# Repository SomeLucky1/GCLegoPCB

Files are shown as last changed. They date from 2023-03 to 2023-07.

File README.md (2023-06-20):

# Gaggiuino LegoPCB

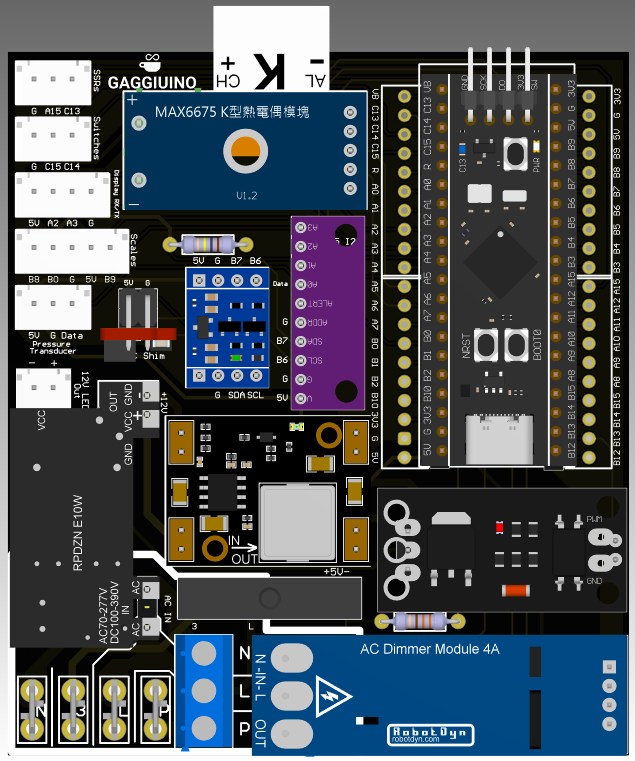
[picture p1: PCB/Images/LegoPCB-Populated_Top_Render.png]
Fully Populated


Gaggiuino has two options for assembly, "Lego" and PCB. While a nice case is available for the Lego components, there is not a good way to keep it looking clean. The primary objective of this project is to provide an option of using the Lego components, with minimal modifiction, and avoid the interconnected wire mess. LegoPCB effectively provides a wire harness on a PCB for the most of the Lego components. An SSR has been substituted as the relay used for the solenoid valve.

---
<br>

## Projects
- ### [CircuitMaker](https://workspace.circuitmaker.com/Projects/Details/somelucky/Gaggiuino-Lego-PCB-QWIIC)

- ### [PCBWay](https://www.pcbway.com/project/shareproject/Gaggiuino_Lego_PCB_872e6bd4.html)

- ### [Gaggiuino](https://gaggiuino.github.io/#/)

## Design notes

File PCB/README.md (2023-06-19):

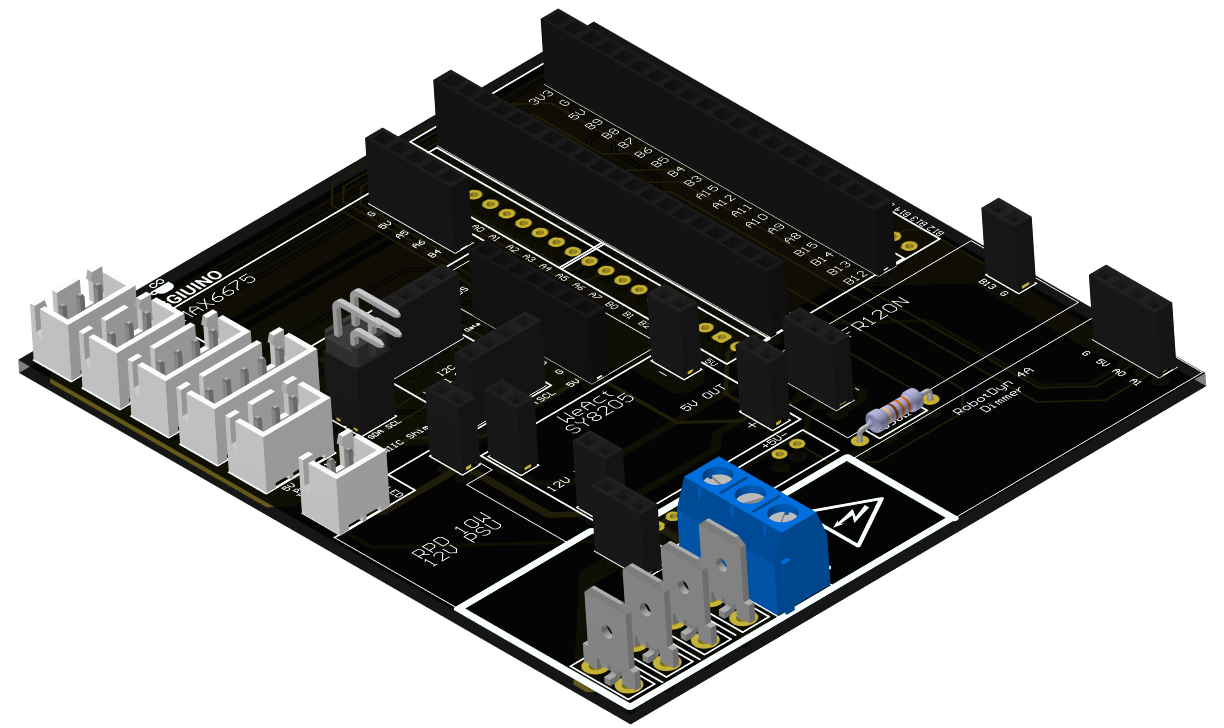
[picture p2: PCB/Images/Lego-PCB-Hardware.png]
PCB Populated


Top|Bottom
:---:|:---:
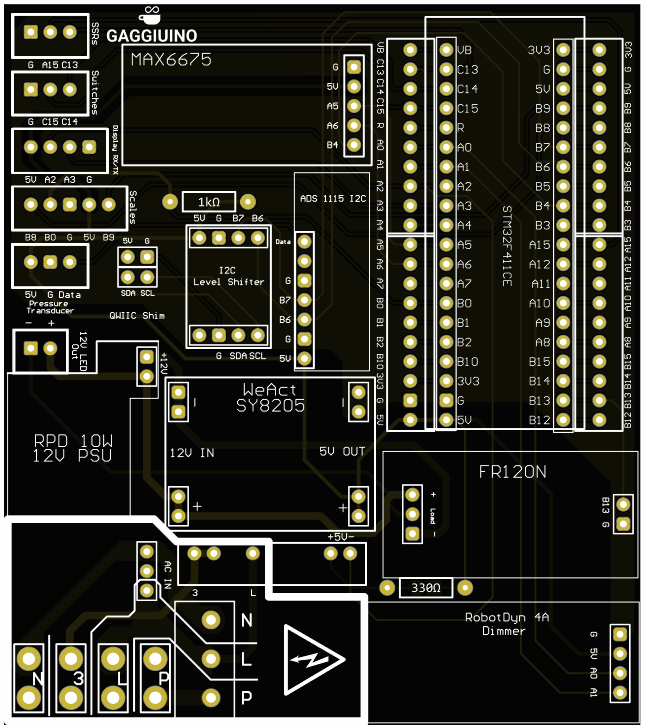
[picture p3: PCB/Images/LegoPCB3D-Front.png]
PCB Front
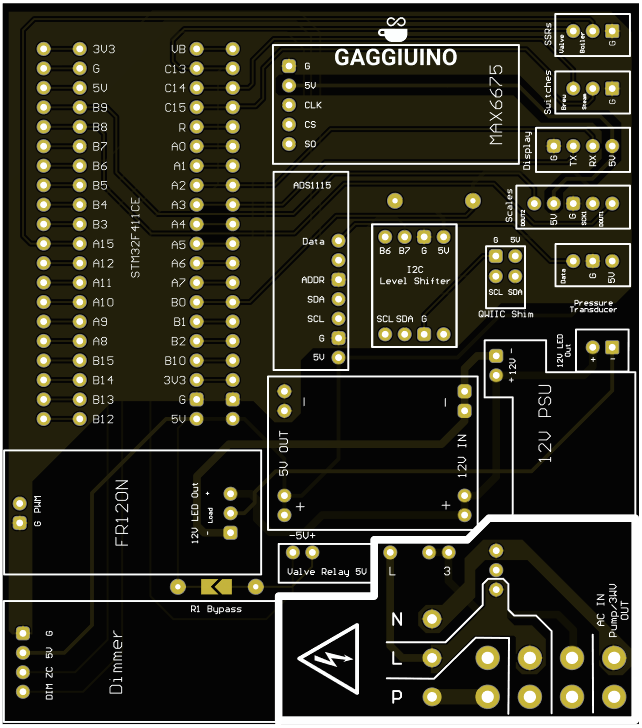
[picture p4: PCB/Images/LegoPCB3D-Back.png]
PCB Back
|

<a name="comingsoon">

### <b>Coming Soon</b> 

QWIIC connector with I²C 3.3V regulation.

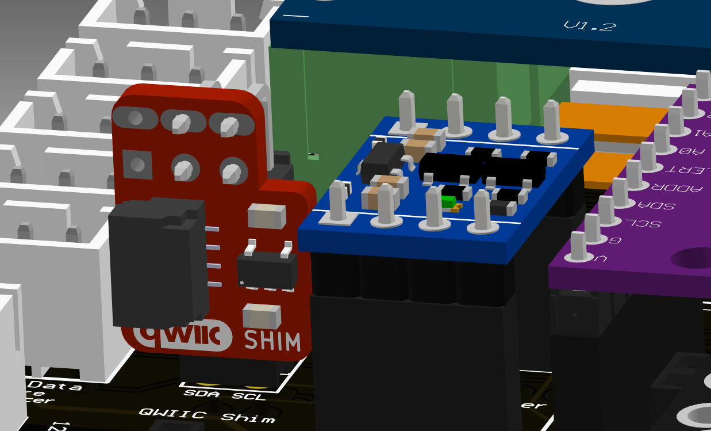
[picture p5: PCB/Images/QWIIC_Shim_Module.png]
QWIIC Module

</a>

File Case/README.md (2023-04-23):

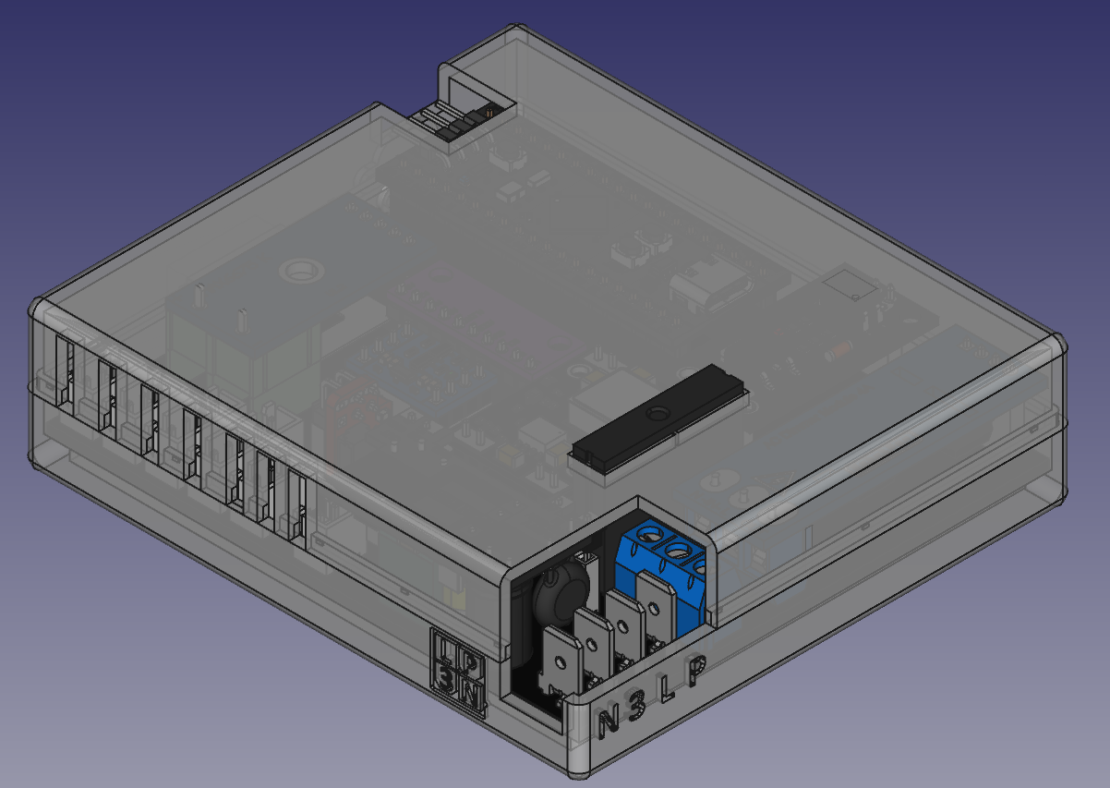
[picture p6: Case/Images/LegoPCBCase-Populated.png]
Case with PCB


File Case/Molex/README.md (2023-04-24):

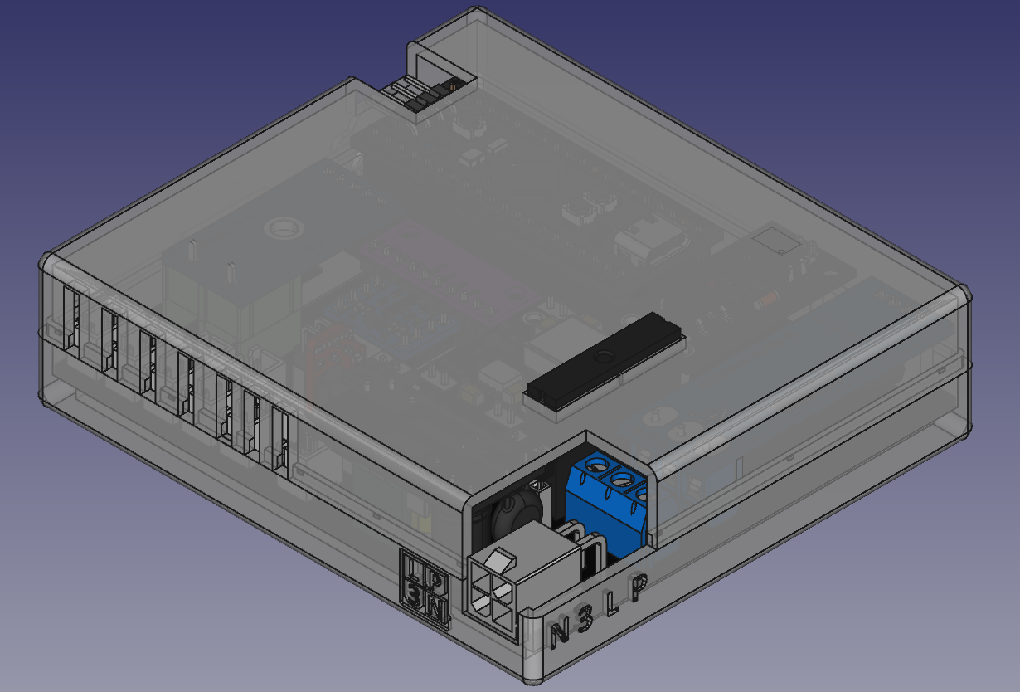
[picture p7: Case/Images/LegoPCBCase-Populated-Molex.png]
PCB Case - Molex

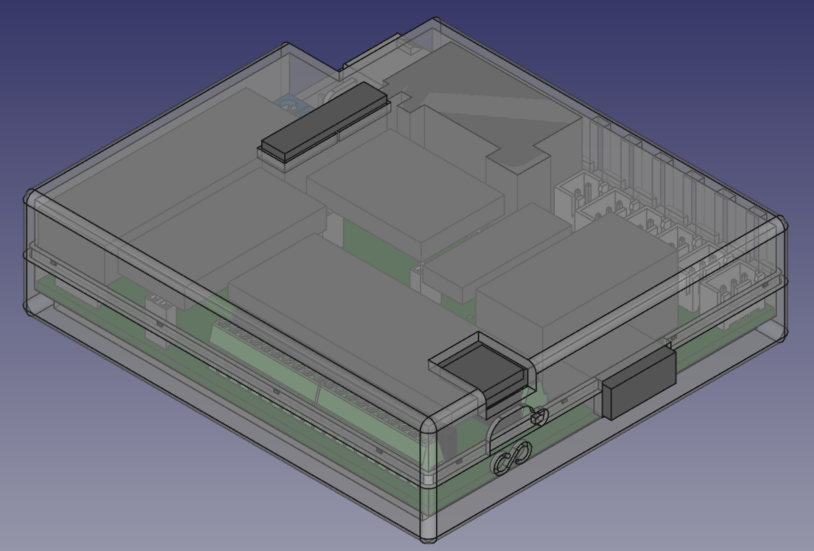
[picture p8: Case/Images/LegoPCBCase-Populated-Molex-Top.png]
PCB Case - Molex


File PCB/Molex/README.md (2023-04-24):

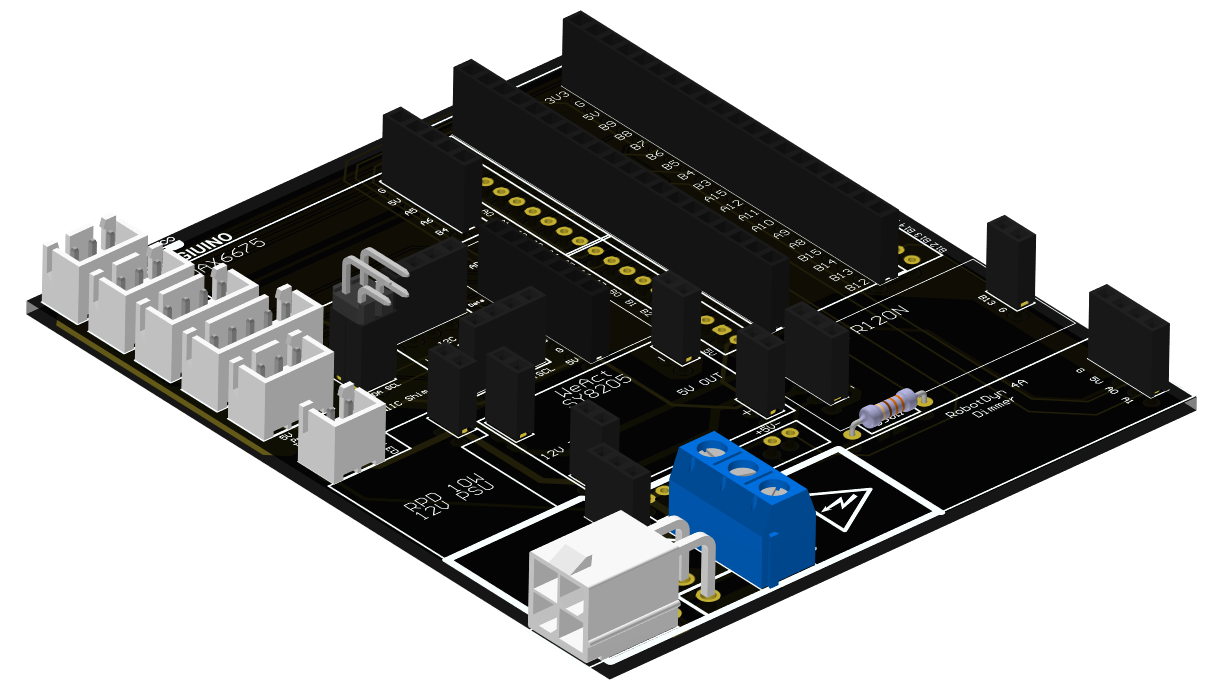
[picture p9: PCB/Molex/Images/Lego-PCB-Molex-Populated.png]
Lego PCB-Molex-Populated

Top|Bottom
:---:|:---:
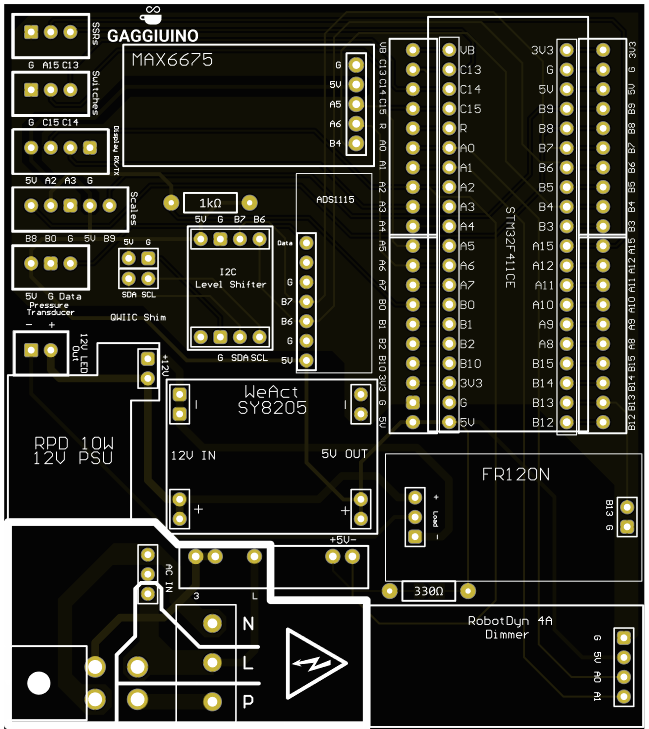
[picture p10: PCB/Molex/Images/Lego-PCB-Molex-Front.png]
Lego PCB-Molex-Front
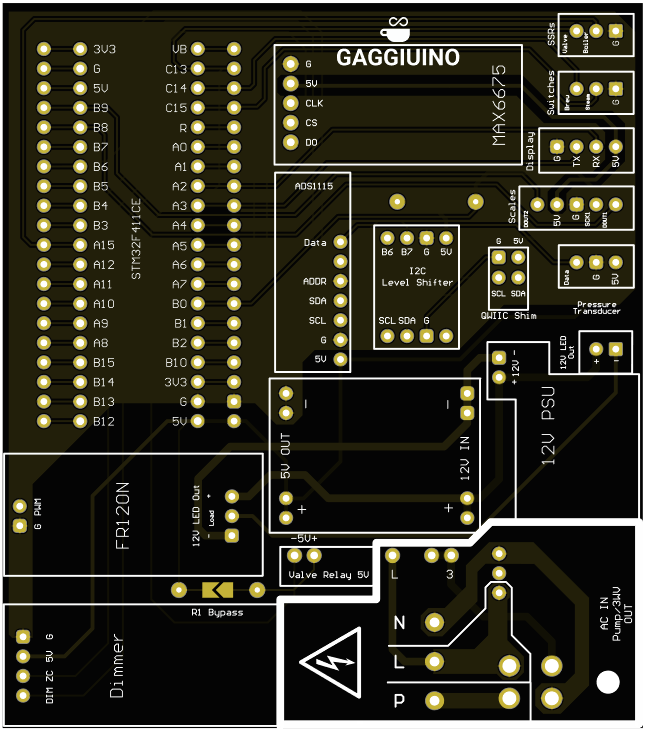
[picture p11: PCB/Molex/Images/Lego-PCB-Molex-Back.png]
Lego PCB-Molex-Back
|

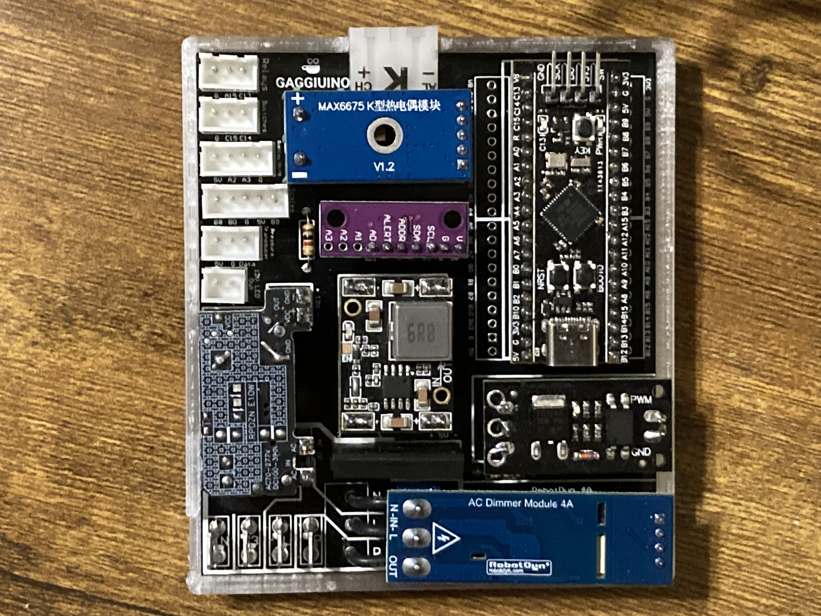
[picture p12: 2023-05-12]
PCB/Images/LegoPCB_Populated.JPG

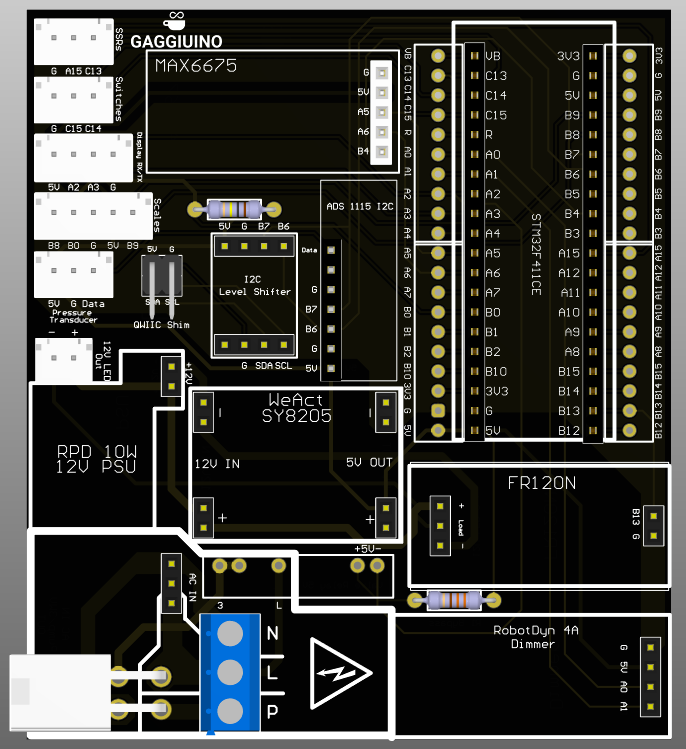
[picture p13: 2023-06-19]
PCB/Molex/Images/LegoPCB-Molex-QWIIC-Top.png

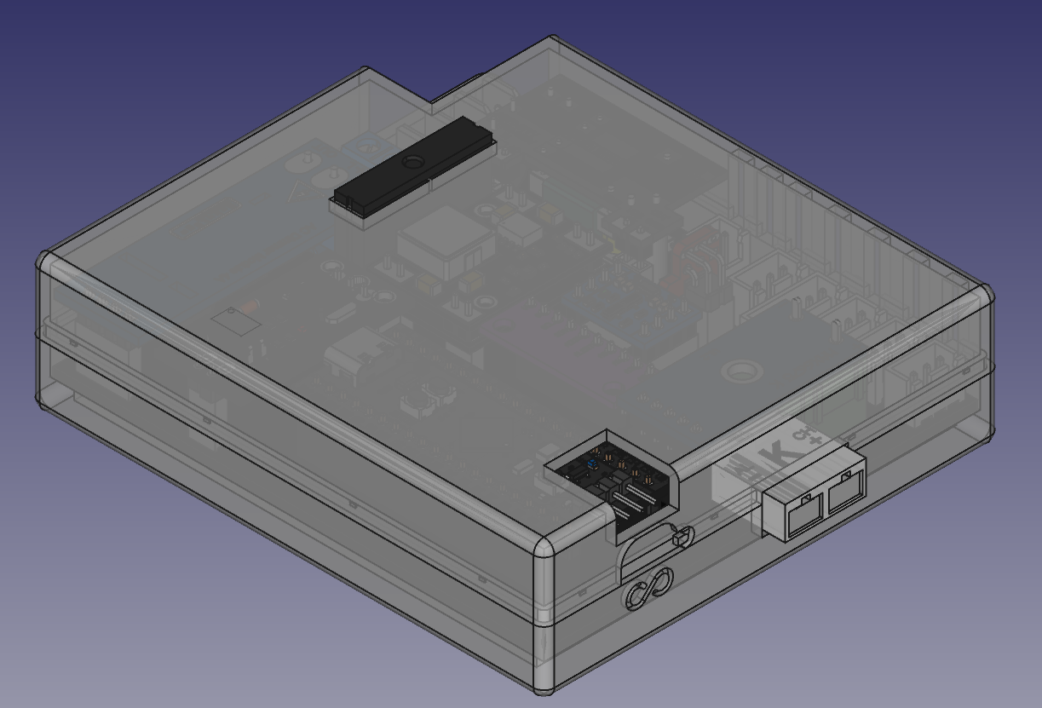
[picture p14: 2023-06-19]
Case/Images/LegoPCBCase-Populated-Top.png

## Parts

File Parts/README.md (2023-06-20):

## Soldered Components

- ### JST-XH 2.54mm Male Headers
    - 3x 3P (Boiler SSR,Brew/Steam Switches,Pressure Transducer)
    - 1x 2P (12V LED)
    - 1x 4P (Display)
    - 1x 5P (Scales)
    
    <br>
- ### Male Pin Headers
    - 28x 11.5mm
    - 4x 15mm
    - (optional) 1x 2x2 right angle 3mm/6mm board/header

    <br>
- ### Female Pin Headers
    - 8x 2P (5V PSU,12V PSU,FR120N, QWIIC Shim)
    - 2x 20P (Blackpill)
    - 2x 3P (12V PSU,FR120N)
    - 1x 7P (ADS1115)
    - 1x 5P (MAX6675)
    - 3x 4P (Dimmer, I²C Shifter)

    <br>
- ### Screw Terminals
    - 1x 3P 5mm pitch - Bundled with most FR120N preassembled boards
    - (optional) 4x 10P 2.54mm pitch

    <br>
- ### Power/3WV/Pump Connections
    - 4x Male blade quick connect terminals
    - (optional) Molex 4P Mini Fit Jr. 90 degree mount -- for use with Molex Power design PCB

    <br>
- ### Resistors ¼W
    - 1x 1kΩ - for use with hardware scales
    - (optional) 1x 330Ω - If 3WV SSR requires

    <br>
- ### 3-Way Solenoid Valve SSR (choose one)
    - Omron G3MB-202P 5V - No input resistor requried (short R1 Bypass solder pad)
    - Panasonic AQG12105 - Input resistor required

    <br>

## Lego Part Modifications
Part|3D Model|Mod
---|---|---
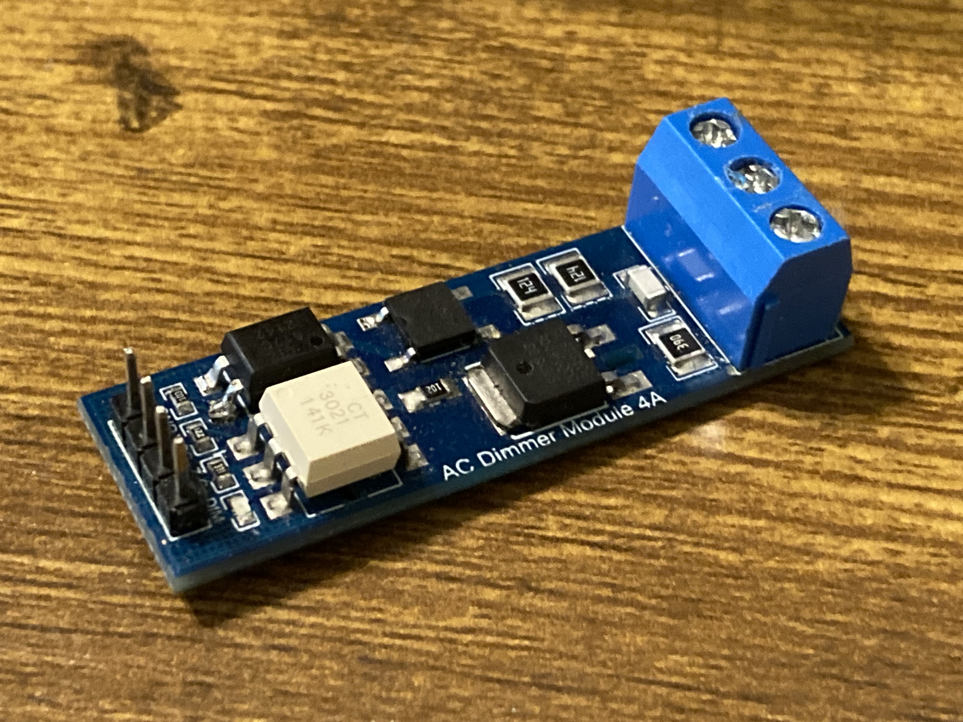
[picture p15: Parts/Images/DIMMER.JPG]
Dimmer
|[STL](/Parts/Images/STL/RDDimmer.stl "Dimmer") <br> [STEP](/Parts/Images/STEP/RDDimmer.step "Dimmer")|No modifications required
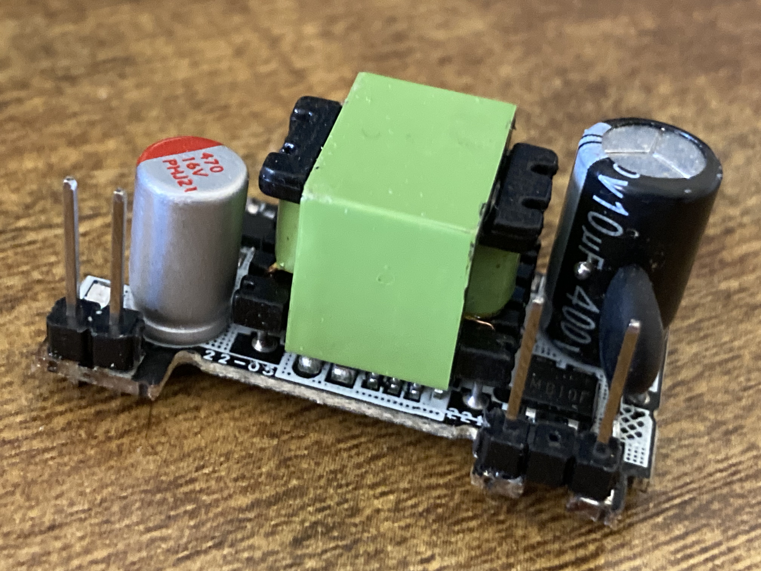
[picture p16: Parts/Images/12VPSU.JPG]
12V PSU
|[STL](/Parts/Images/STL/12V1APSU.stl "12VPSU") <br> [STEP](/Parts/Images/STEP/12V1APSU.step "12VPSU")|Use 15mm male pin headers
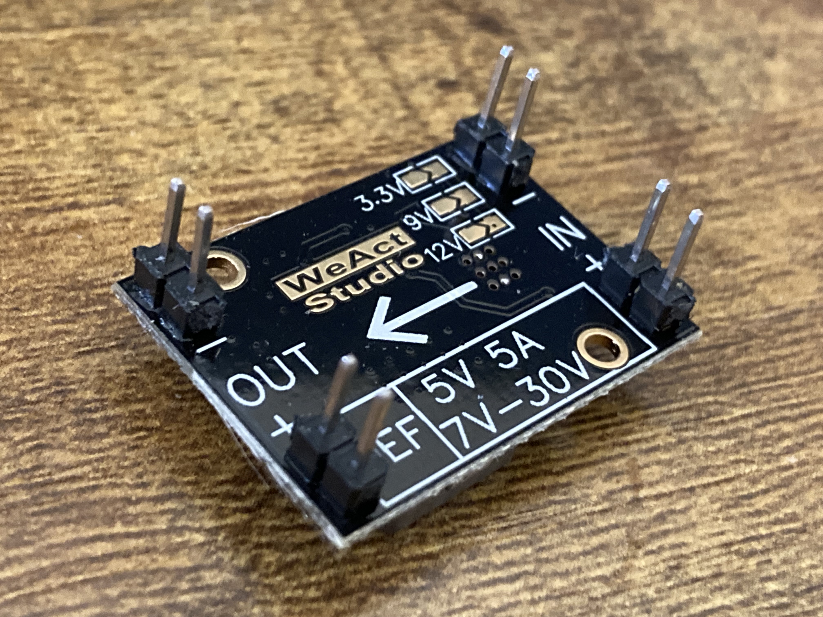
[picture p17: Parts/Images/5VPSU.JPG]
5V PSU
|[STL](/Parts/Images/STL/SY8205.stl "5VPSU") <br> [STEP](/Parts/Images/STEP/SY8205.step "5VPSU")|Use 11.5mm male pin headers
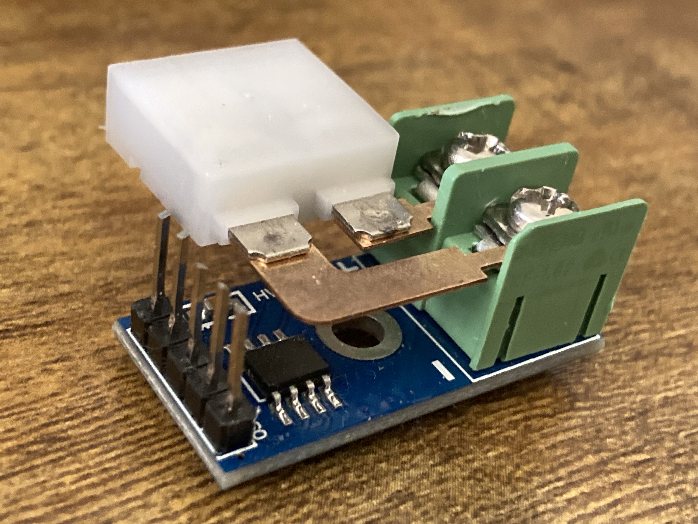
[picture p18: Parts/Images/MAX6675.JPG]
MAX6675
|[STL](/Parts/Images/STL/MAX6675.stl "MAX6675") [STL](/Parts/Images/STL/KPlugPCBMount.stl "KPLUG")<br> [STEP](/Parts/Images/STEP/MAX6675BB.step "MAX6675") [STEP](/Parts/Images/STEP/KPlugPCBMount.step "KPLUG")|Straighten pins<br><br>(optional) Use PCB mountable female mini K-type plug
TCM4 TC Sensor - M4||(optional) Use male mini K-type plug
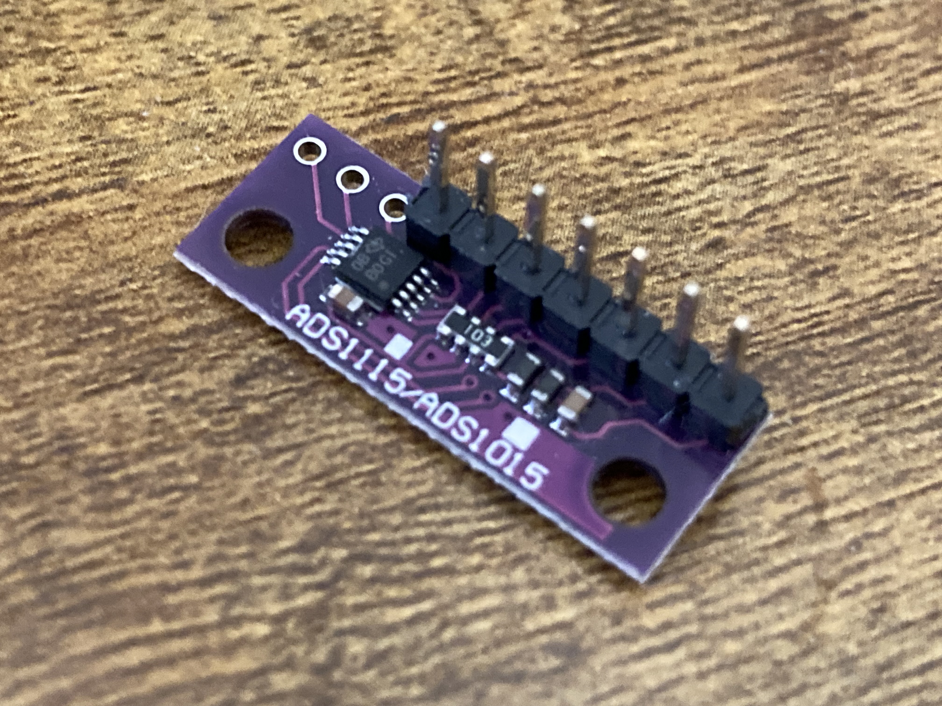
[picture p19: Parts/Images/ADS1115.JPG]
ADS1115
|[STL](/Parts/Images/STL/ADS1115.stl "ADS1115") <br> [STEP](/Parts/Images/STEP/ADS1115BB.step "ADS1115")|Use 11.5mm male pin headers
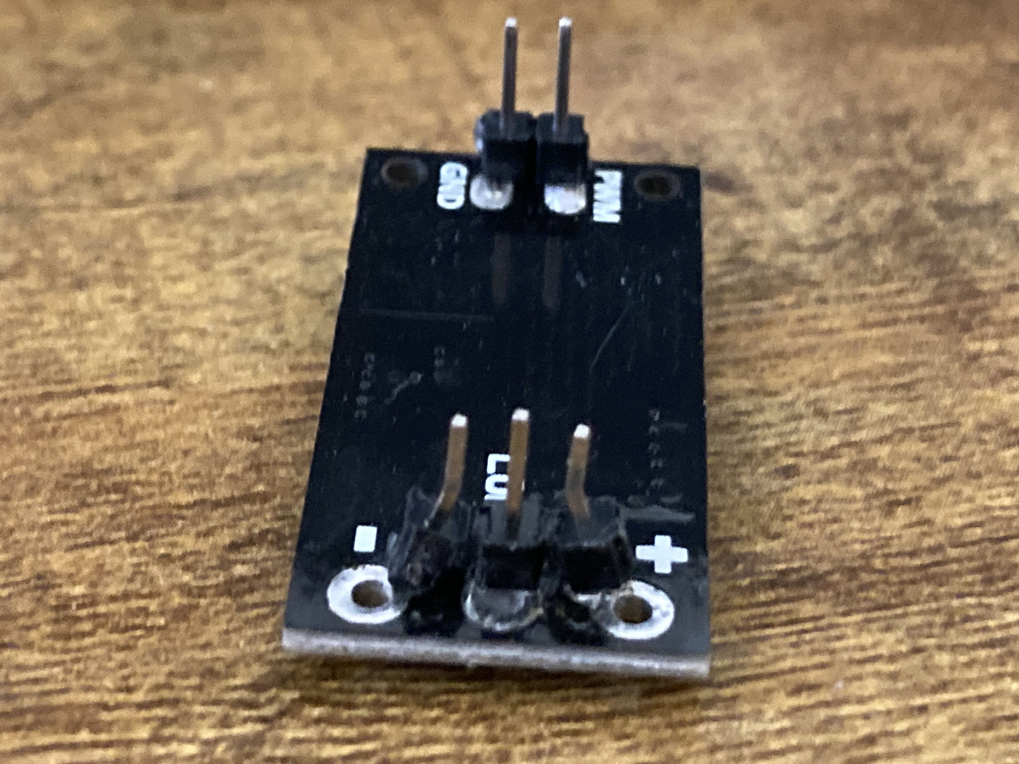
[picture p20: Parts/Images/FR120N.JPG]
FR120N
|[STL](/Parts/Images/STL/MosfetBoard.stl "FR120N") <br> [STEP](/Parts/Images/STEP/MosfetBoard.step "FR120N")|Use 11.5mm male pin headers<br><br>Bend 12V/Load pins to 2.54mm pitch width
QWIIC SHIM|[STL](/Parts/Images/STL/LevelConverter.stl "Level Shifter") [STL](/Parts/Images/STL/QWIICShim.stl "QWIIC Shim") <br> [STEP](/Parts/Images/STEP/LevelConverter.step "Level Shifter") [STEP](/Parts/Images/STEP/QWIIC%20SHIM.step "QWIIC Shim")|  Qwiic connector and I²C 3.3V regulation module.

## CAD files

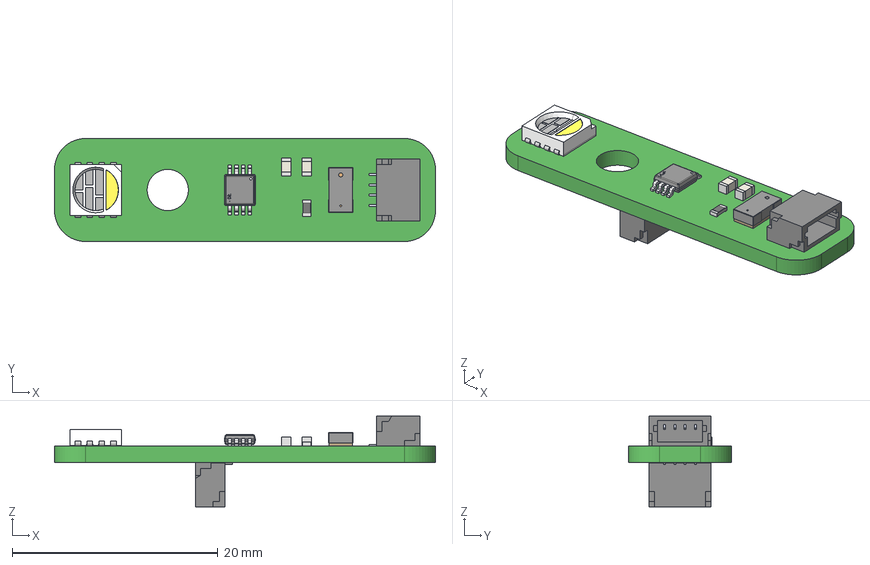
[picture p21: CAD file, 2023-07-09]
Accessories/Images/STEP/ToFnLED-RGBW.step
37.0 x 10.0 x 8.80 mm
NXP Logo
Solder Mask Ext
PCB
Solder Pads
Large Sensor Cover
Small Sensor Cover
Chamfered Case
User Library-res0603-1
SPARKFUN_QWIIC_RIGHT_ANGLE
Conn_JST_BM04B-SRSS-TB_LF_SN_eec_RGB4210752
LED Traces
White LED
Pin7
Pin3
Pin4
Pin2
Pin1
Pin5
Pin6
Pin8
Extruded x 6

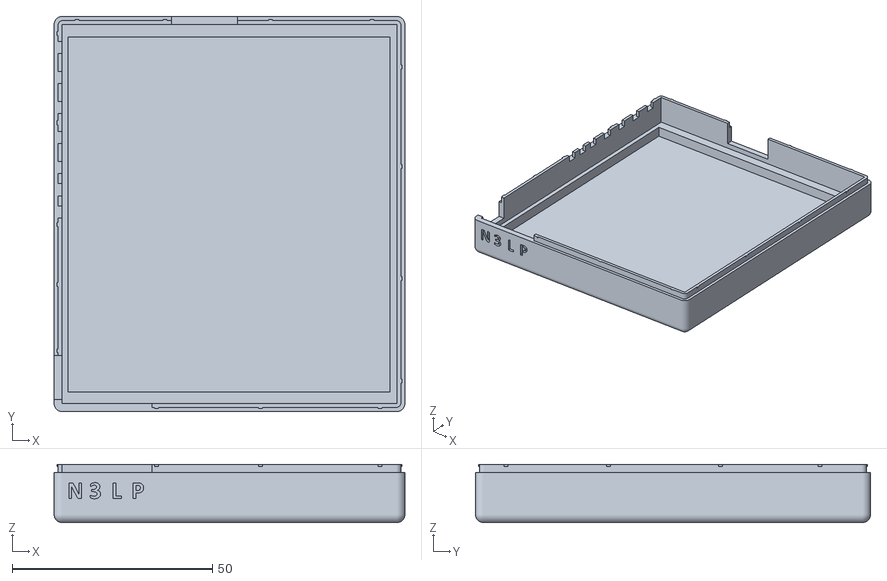
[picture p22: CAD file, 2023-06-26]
Case/PCB Case-Bottom.stl
87.5 x 98.5 x 14.5

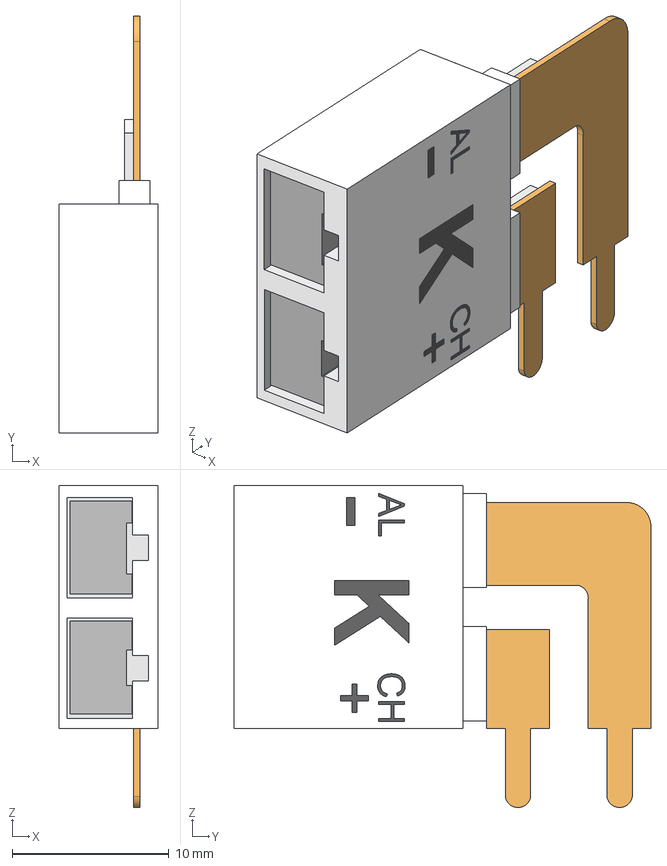
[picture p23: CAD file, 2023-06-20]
Parts/Images/STEP/KPlugPCBMount.step
6.35 x 26.6 x 20.5 mm
Pin Mounts
Joints
Pins Ext
Clamps
K
AL
CH
+

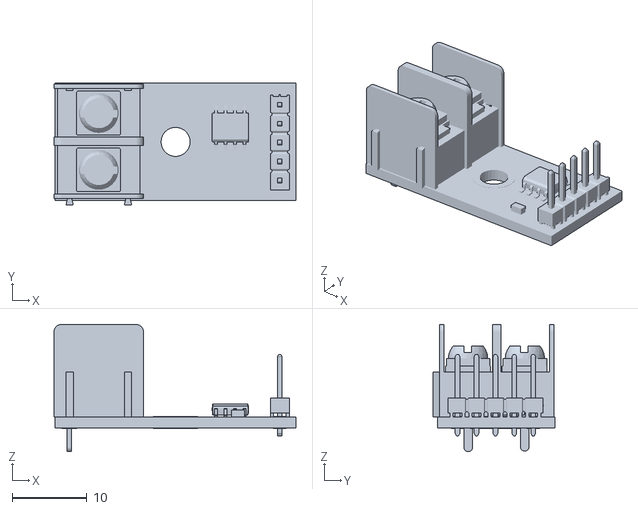
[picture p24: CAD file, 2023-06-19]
Parts/Images/STL/MAX6675.stl
32.5 x 16.3 x 17.1

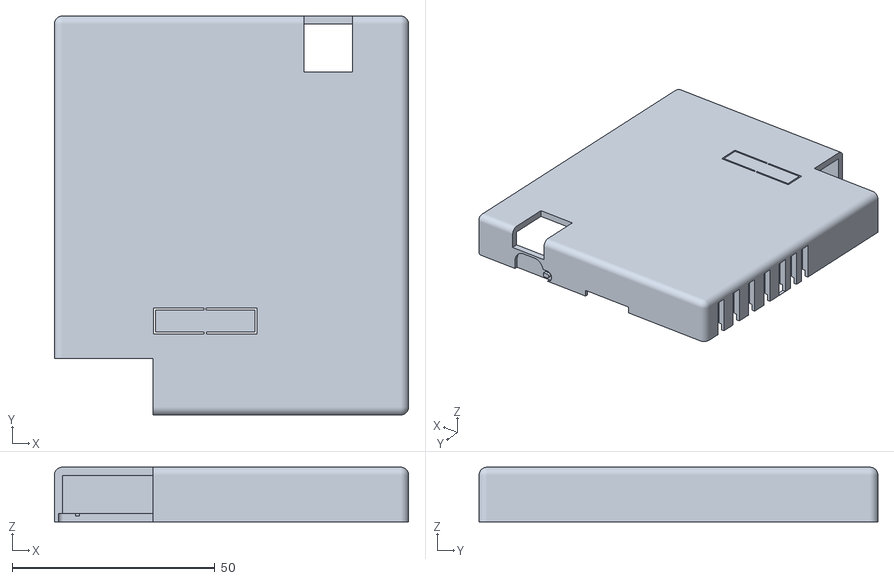
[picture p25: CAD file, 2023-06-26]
Case/PCB Case-Top.stl
87.5 x 98.5 x 13.5

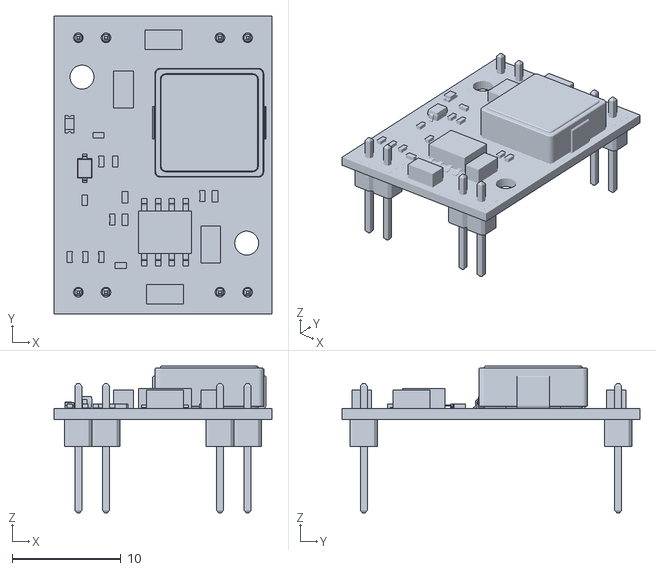
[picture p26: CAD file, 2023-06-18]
Parts/Images/STL/SY8205.stl
20.0 x 27.3 x 13.5

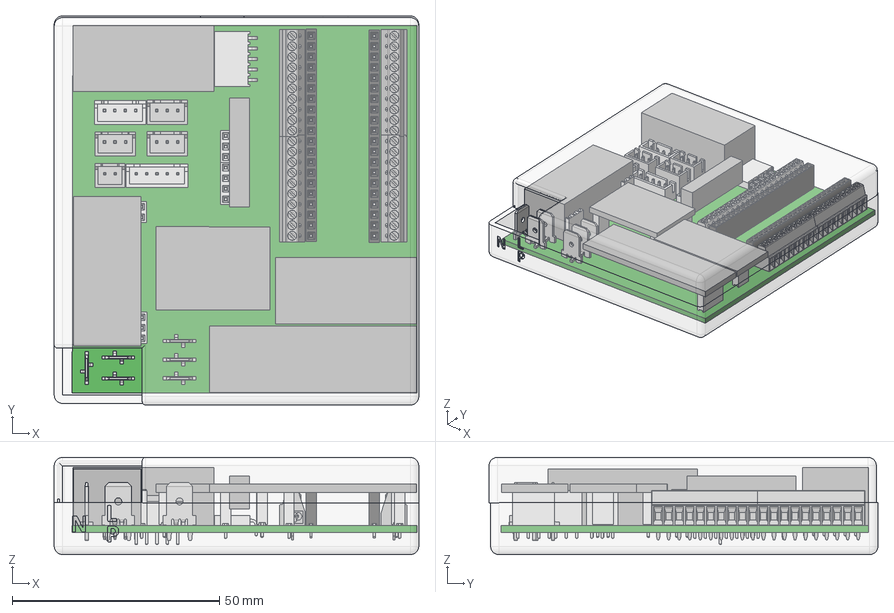
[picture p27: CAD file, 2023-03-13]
Case/PCB Case.FCStd
88.0 x 93.9 x 23.4 mm
User_Library-JST_B5B-XH-A
User_Library-jst-b4b-xh-a-1
JST-XH_-_3Pin_v1
JST-XH_-_3Pin_v002
JST-XH_-_3Pin_v003
JST-XH_-_2Pin_v1
c-63824-1-ad-3d_RGB11579568
c-63824-1-ad-3d_RGB11579569
c-63824-1-ad-3d_RGB11579570
c-63824-1-ad-3d_RGB11579571
c-63824-1-ad-3d_RGB11579572
c-63824-1-ad-3d_RGB11579573
User_Library-ZL262-3SG
User_Library-ZL262-2SG
User_Library-ZL262-4SG
User_Library-ZL262-3SG001
User_Library-ZL262-4SG001
User_Library-ZL262-2SG001
User_Library-ZL262-2SG002
User_Library-ZL262-3SG002
User_Library-ZL262-2SG003
User_Library-ZL262-2SG004
User_Library-ZL262-2SG005
SSQ-105-02-X-S-RA
Base_with_top_bottom_inside_cut
Pins_Ext
Base_with_top_bottom_inside_cut001
Pins_Ext001
Extruded
Extruded001
Extruded002
Extruded003
Extruded004
Extruded005
Top Case
Bottom Case

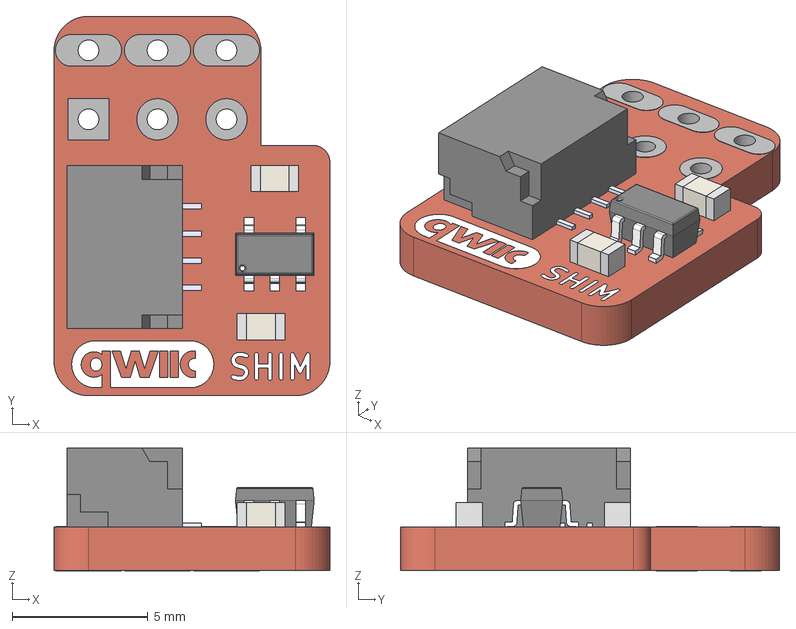
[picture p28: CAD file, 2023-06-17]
Parts/Images/STEP/QWIIC SHIM.step
10.2 x 14.0 x 4.52 mm
Pin Solder Pads
Logo
SOT23-5_D
SPARKFUN_QWIIC_RIGHT_ANGLE
Extruded x 4
Extruded013 x 2

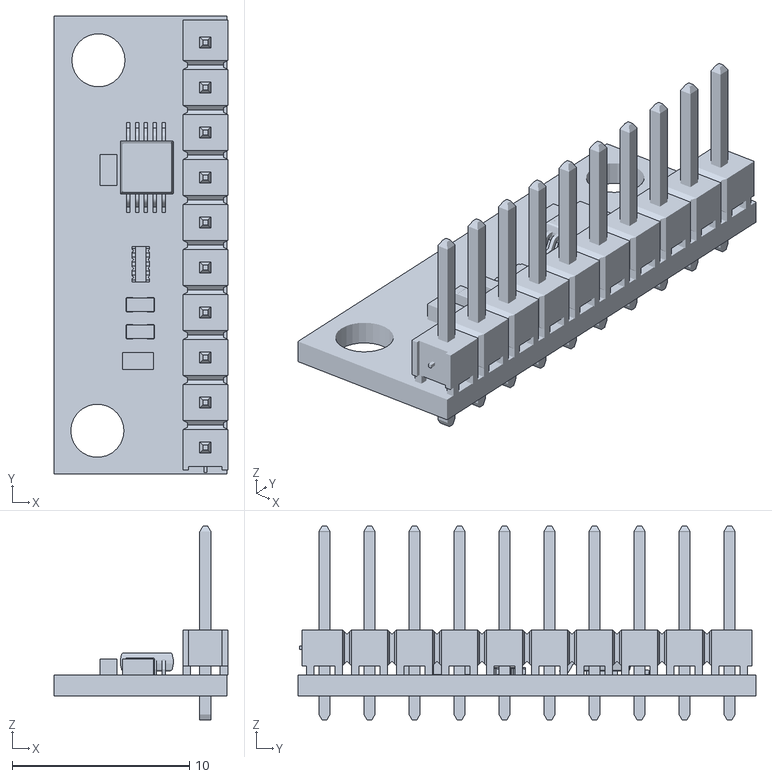
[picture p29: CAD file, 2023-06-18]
Parts/Images/STL/ADS1115.stl
9.81 x 25.8 x 10.9

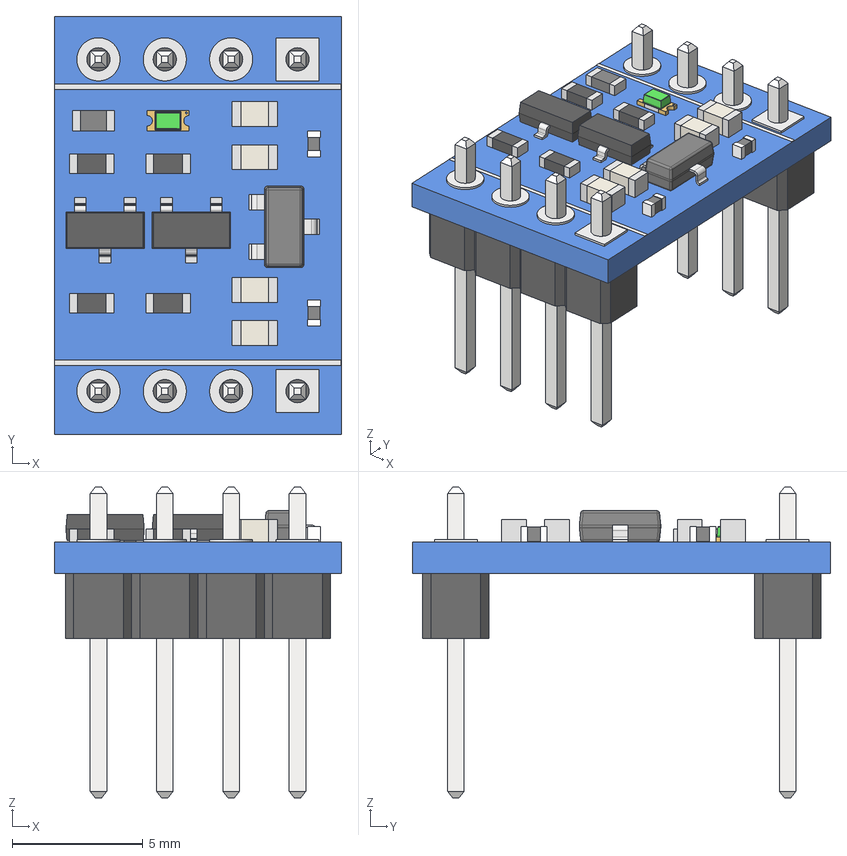
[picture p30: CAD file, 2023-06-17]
Parts/Images/STEP/LevelConverter.step
11.0 x 16.0 x 11.9 mm
Rectangle
Rectangle001
5V
GND
HV1
HV2
3V3
GND001
LV1
LV2
LevelConverter
WE-VS_0402_VS002 x 2
Leg008 x 8
Extruded027 x 8
Extruded029 x 4
User Library-LED_0603_G_Pocket003
User Library-LED_0603_G_Pad005
User Library-LED_0603_G_Fillet001
User Library-LED_0603_G_Pocket004
User Library-LED_0603_G_Pad006
Extruded039 x 8
Extruded041 x 4
Leader003 x 3
Extruded042 x 2
Extruded043
SW3DPS-SOT-23-DEFAULT002 x 2

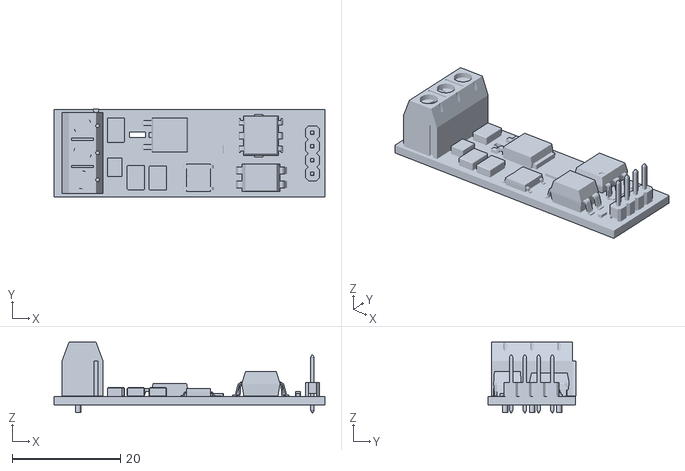
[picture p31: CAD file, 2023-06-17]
Parts/Images/STL/RDDimmer.stl
50.1 x 16.3 x 13.1

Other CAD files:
Parts/Images/STEP/MAX6675BB.step
Parts/Images/STL/KPlugPCBMount.stl
Parts/Images/STL/LevelConverter.stl
Parts/Images/STL/QWIICShim.stl

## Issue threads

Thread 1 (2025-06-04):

ADS1115 is connected directly to STM32 without level shifter

dkaukov, 2025-06-04:
Noticed that the ADS1115 (running at 5V) is connected directly to the STM32's I2C lines (3.3V). There's a level shifter on the board, but it's only used for the QWIIC connector—not the ADS1115.

Is this a design choice or maybe just an oversight? Seems risky for the STM32 and could cause communication issues, but maybe there's a reason for it?

SomeLucky1, 2025-06-21:
The STM32 is 5V tolerant.  The ADS1115 must run at 5V to match the voltage of the pressure sensor.

Closed 2025-06-21.

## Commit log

2023-03-13 First real commit
    [PCB Case -Bottom Case.stl, PCB Case -Top Case.stl, PCB Case.FCStd]
2023-04-13 New revisions of PCB and Case
    [LegoPCB.SchDoc, PCB Case -Bottom Case.stl, PCB Case -Bottom.stl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]
2023-04-26 Case updates
    [PCB Case-Bottom.stl, PCB Case-Top.stl]
2023-04-26 Case images updated
2023-06-17 3d models
    [LevelConverter.step, LevelConverter.stl, MAX6675BB.step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]
2023-06-19 Board Render shots Updated
2023-06-19 New Shim and i2c regulator angle
2023-06-19 Case Updates and new 3D renders
    [MAX6675.stl, MAX6675BB.step]
2023-06-20 Point to updated CM Project
    [LegoPCB.SchDoc]
2023-07-09 Future Accessories page
    [ToFnLED-RGBW.step]
2025-05-18 KiCad project
2025-05-18 Remove old project
    [LegoPCB.SchDoc]
